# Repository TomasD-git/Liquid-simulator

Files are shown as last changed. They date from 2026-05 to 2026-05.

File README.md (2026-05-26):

# Liquid-simulator
Basically simulates liquid using imu and esp32 C6






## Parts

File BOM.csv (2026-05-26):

Name | Purpose | Quantity | Total Cost (USD) | Link | Distributor
Mini hot plate | will be used to melt the solder paste to connect components to pcb | 1 | 39.54 | https://www.aliexpress.com/item/1005007987545003.html | Aliexpress
Screen | on the screen is the actual simulation | 1 | 3.74 | https://www.aliexpress.com/item/1005004482028005.html | Aliexpress
PCB + Stencil | actual pcb which all components will be on | 1 | 36.62 | https://jlcpcb.com | JLCPCB
LCSC parts | all individual parts | 1 | 24.01 | https://lcsc.com | lcsc

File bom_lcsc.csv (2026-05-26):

Designator | Footprint | Quantity | Value | LCSC Part #
C1, C3, C5 | 0603 | 3 | 10uF | C1691
C10, C23 | 0402 | 2 | 1uF | C52923
C13, C24, C25, C7, C8, C9 | 0402 | 6 | 100nf | C1525
C2, C4 | 0603 | 2 | 1uF | C15849
C6 | 0805 | 1 | 47uF | C16780
J2 | PinHeader_1x07_P2.54mm_Vertical | 1 | Display 1.28 Inch
R1, R2 | 0402 | 2 | 22 | C25092
R10, R7 | 0402 | 2 | 5.1K | C25905
R3, R4 | 0402 | 2 | 2.2K | C25879
R5, R8 | 0402 | 2 | 10K | C25744
R6 | 0402 | 1 | 330 | C25104
SW1, SW2 | SW_Push_1P1T_XKB_TS-1187A | 2 | SW_Push | C318884
U1 | USB-C-SMD_G-SWITCH_GT-USB-7010ASV | 1 | GT-USB-7010ASV | C2988369
U2 | SOT-23-5 | 1 | AP2112K-3.3 | C51118
U4 | XDCR_BMI270 | 1 | BMI270 | C2836813
U5 | ESP32-C6-MINI-1 | 1 | ESP32-C6-MINI-1/U | C5736265

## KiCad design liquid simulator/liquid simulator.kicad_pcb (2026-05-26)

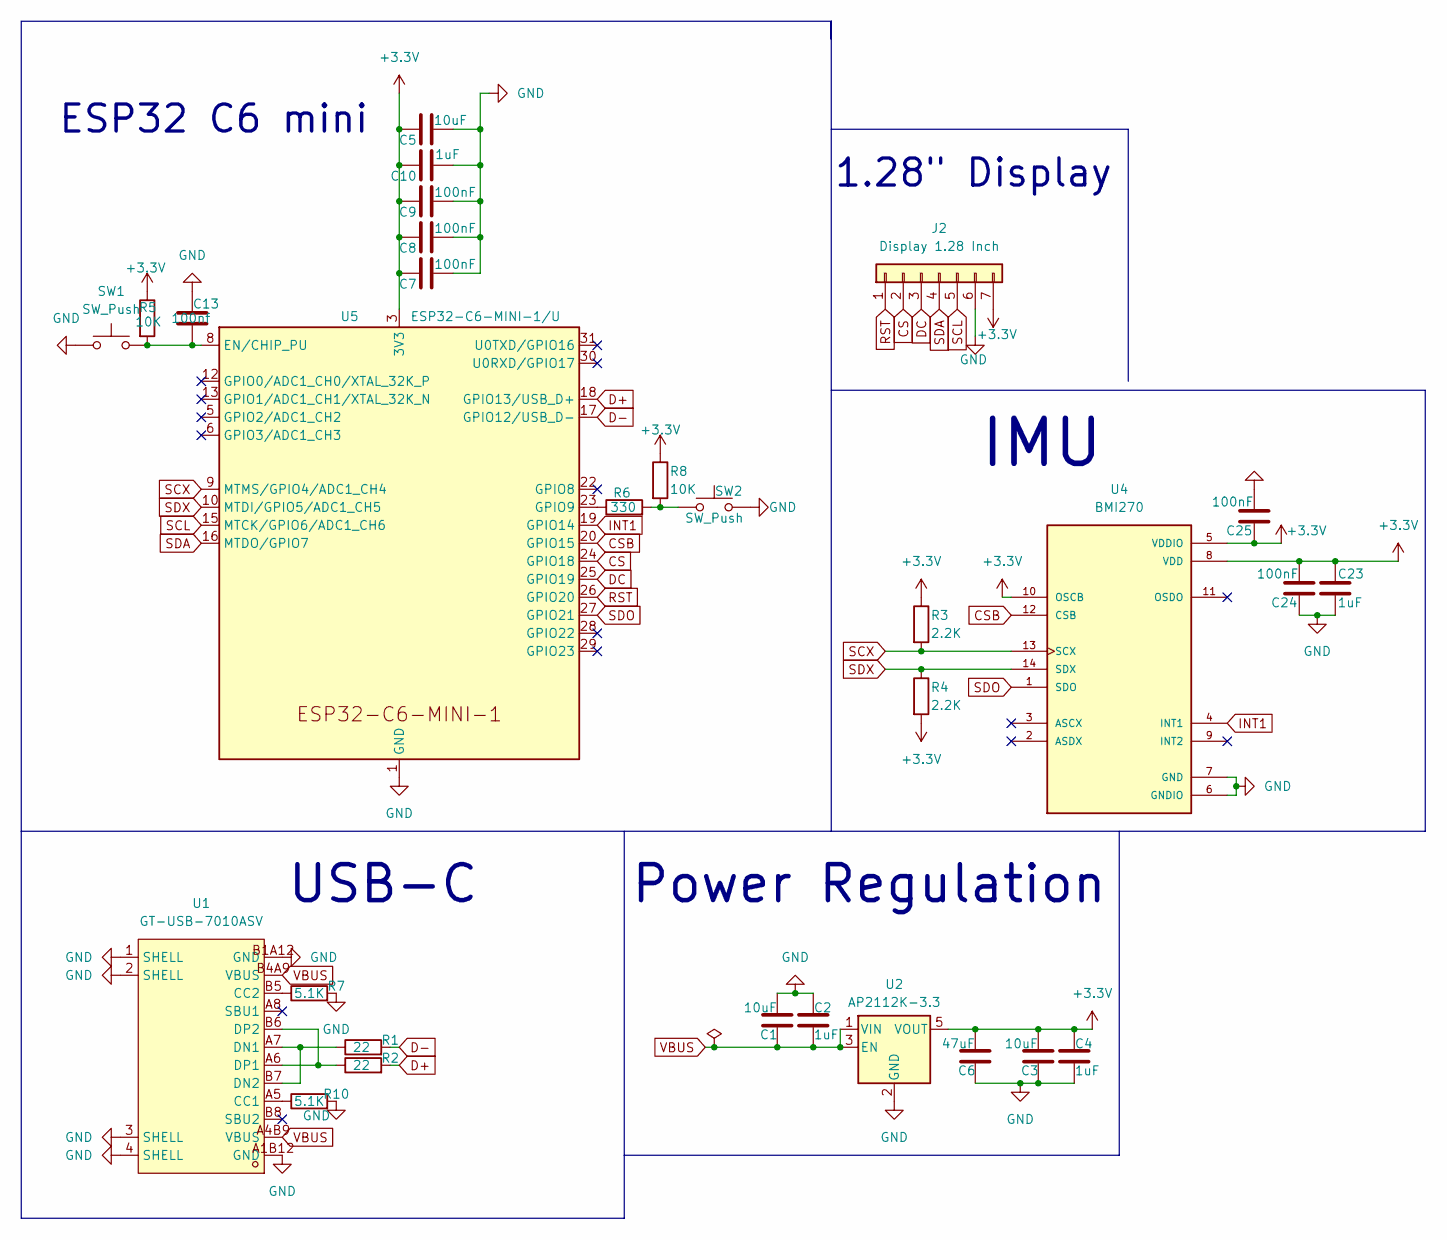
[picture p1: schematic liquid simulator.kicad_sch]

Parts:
C1, C3, C5: 10uF; C_0603_1608Metric
C2, C4: 1uF; C_0603_1608Metric
C6: 47uF; C_0805_2012Metric
C7, C8, C9, C24, C25: 100nF; C_0402_1005Metric
C10, C23: 1uF; C_0402_1005Metric
C13: 100nf; C_0402_1005Metric
J2: Display 1.28 Inch; PinHeader_1x07_P2.54mm_Vertical
R1, R2: 22; R_0402_1005Metric
R3, R4: 2.2K; R_0402_1005Metric
R5, R8: 10K; R_0402_1005Metric
R6: 330; R_0402_1005Metric
R7, R10: 5.1K; R_0402_1005Metric
SW1, SW2: SW_Push; SW_Push_1P1T_XKB_TS-1187A
U1: GT-USB-7010ASV; USB-C-SMD_G-SWITCH_GT-USB-7010ASV; MPN GT-USB-7010ASV; LCSC Part C2988369
U2: AP2112K-3.3; SOT-23-5
U4: BMI270; XDCR_BMI270
U5: ESP32-C6-MINI-1/U; ESP32-C6-MINI-1

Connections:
+3.3V: C3.1, C4.1, C5.1, C6.1, C7.1, C8.1, C9.1, C10.1, C23.1, C24.1, C25.2, J2.7, R3.1, R4.2, R5.1, R8.1, U2.5 (VOUT), U4.5 (VDDIO), U4.8 (VDD), U4.10 (OSCB), U5.3 (3V3)
CS: J2.2, U5.24 (GPIO18)
CSB: U4.12 (CSB), U5.20 (GPIO15)
D+: R2.2, U5.18 (GPIO13/USB_D+)
D-: R1.2, U5.17 (GPIO12/USB_D-)
DC: J2.3, U5.25 (GPIO19)
GND: C1.1, C2.1, C3.2, C4.2, C5.2, C6.2, C7.2, C8.2, C9.2, C10.2, C13.1, C23.2, C24.2, C25.1, J2.6, R7.2, R10.2, SW1.1, SW2.2, U1.1 (SHELL), U1.2 (SHELL), U1.3 (SHELL), U1.4 (SHELL), U1.A1B12 (GND), U1.B1A12 (GND), U2.2 (GND), U4.6 (GNDIO), U4.7 (GND), U5.1 (GND), U5.2 (GND), U5.11 (GND), U5.14 (GND), U5.36 (GND), U5.37 (GND), U5.38 (GND), U5.39 (GND), U5.40 (GND), U5.41 (GND), U5.42 (GND), U5.43 (GND), U5.44 (GND), U5.45 (GND), U5.46 (GND), U5.47 (GND), U5.48 (GND), U5.49 (GND), U5.50 (GND), U5.51 (GND), U5.52 (GND), U5.53 (GND)
INT1: U4.4 (INT1), U5.19 (GPIO14)
unnamed: R6.2, R8.2, SW2.1
unnamed: R10.1, U1.A5 (CC1)
unnamed: R7.1, U1.B5 (CC2)
unnamed: R1.1, U1.A7 (DN1), U1.B7 (DN2)
unnamed: R2.1, U1.A6 (DP1), U1.B6 (DP2)
unnamed: C13.2, R5.2, SW1.2, U5.8 (EN/CHIP_PU)
unnamed: R6.1, U5.23 (GPIO9)
RST: J2.1, U5.26 (GPIO20)
SCL: J2.5, U5.15 (MTCK/GPIO6/ADC1_CH6)
SCX: R3.2, U4.13 (SCX), U5.9 (MTMS/GPIO4/ADC1_CH4)
SDA: J2.4, U5.16 (MTDO/GPIO7)
SDO: U4.1 (SDO), U5.27 (GPIO21)
SDX: R4.1, U4.14 (SDX), U5.10 (MTDI/GPIO5/ADC1_CH5)
VBUS: C1.2, C2.2, U1.A4B9 (VBUS), U1.B4A9 (VBUS), U2.1 (VIN), U2.3 (EN)

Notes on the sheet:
IMU
ESP32 C6 mini
Power Regulation
1.28" Display
USB-C

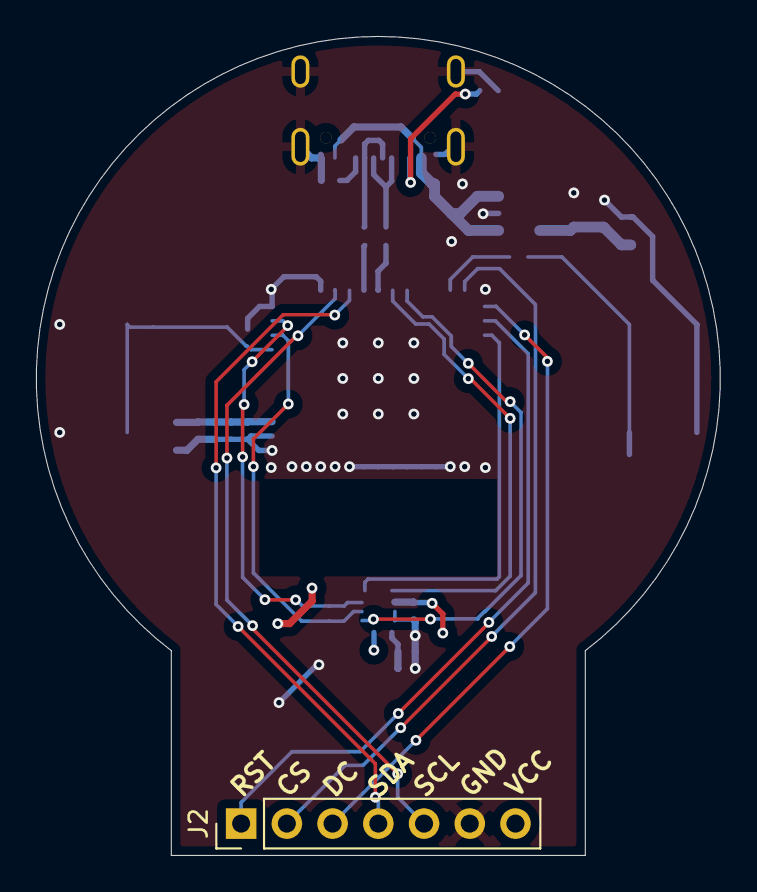
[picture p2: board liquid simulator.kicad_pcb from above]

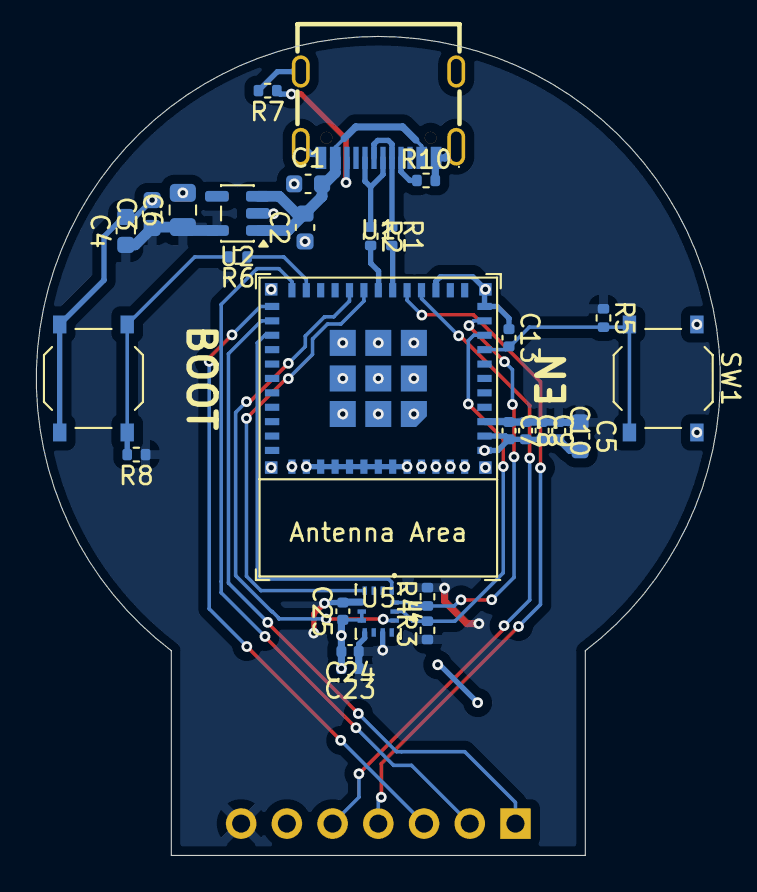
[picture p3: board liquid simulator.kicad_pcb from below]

Board: 2 copper layers, 38.0 x 45.5 mm, 30 parts (29 on the bottom side), 22 nets.

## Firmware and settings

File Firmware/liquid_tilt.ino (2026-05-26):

#include <Arduino.h>
#include <SPI.h>
#include <LovyanGFX.hpp>
#include "lgfx_user.hpp"

LGFX tft;
LGFX_Sprite fb(&tft);


// IMU PINS

#define PIN_IMU_SCK   4
#define PIN_IMU_MOSI  5
#define PIN_IMU_MISO  21
#define PIN_IMU_CS    15
#define PIN_IMU_INT1  14
#define PIN_BTN       9

#define HAVE_BMI270
#include "bmi270_config_file.h"


static SPIClass imuSPI(SPI);

static const int W = 240;
static const int H = 240;
static const int CX = 120;
static const int CY = 120;
static const float RING_R = 116.0f;

static const int NP = 90;
static const float PR = 8.5f;
static const float INTERACT = 22.0f;
static const float I2 = INTERACT * INTERACT;
static const float WALL = RING_R - PR - 1.5f;
static const float DAMP = 0.965f;
static const float G_SCALE = 3.2f;
static const float LP_ALPHA = 0.14f;

struct Particle { float x,y,vx,vy; };
static Particle p[NP];

static float imu_ax = 0;
static float imu_ay = 0;

#define BMI270_REG_CHIP_ID 0x00
#define BMI270_REG_ACC_DATA 0x0C
#define BMI270_REG_ACC_CONF 0x40
#define BMI270_REG_ACC_RANGE 0x41
#define BMI270_REG_PWR_CTRL 0x7D
#define BMI270_REG_PWR_CONF 0x7C
#define BMI270_REG_CMD 0x7E
#define BMI270_REG_INIT_CTRL 0x59
#define BMI270_REG_INIT_ADDR_0 0x5B
#define BMI270_REG_INIT_ADDR_1 0x5C
#define BMI270_REG_INIT_DATA 0x5E
#define BMI270_REG_INTERNAL_STATUS 0x21

static void imuWrite(uint8_t reg, uint8_t val) {
  digitalWrite(PIN_IMU_CS, LOW);
  imuSPI.transfer(reg & 0x7F);
  imuSPI.transfer(val);
  digitalWrite(PIN_IMU_CS, HIGH);
}

static uint8_t imuRead(uint8_t reg) {
  digitalWrite(PIN_IMU_CS, LOW);
  imuSPI.transfer(reg | 0x80);
  imuSPI.transfer(0x00);
  uint8_t v = imuSPI.transfer(0x00);
  digitalWrite(PIN_IMU_CS, HIGH);
  return v;
}

static void imuBurst(uint8_t reg, uint8_t* buf, uint8_t n) {
  digitalWrite(PIN_IMU_CS, LOW);
  imuSPI.transfer(reg | 0x80);
  imuSPI.transfer(0x00);
  for (int i = 0; i < n; i++) buf[i] = imuSPI.transfer(0x00);
  digitalWrite(PIN_IMU_CS, HIGH);
}

bool initBMI270() {
  imuSPI.begin(PIN_IMU_SCK, PIN_IMU_MISO, PIN_IMU_MOSI);
  imuSPI.setFrequency(8000000);
  pinMode(PIN_IMU_CS, OUTPUT);
  digitalWrite(PIN_IMU_CS, HIGH);
  delay(20);
  imuWrite(BMI270_REG_CMD, 0xB6);
  delay(20);
  if (imuRead(BMI270_REG_CHIP_ID) != 0x24) {
    Serial.println("BMI270 not found");
    return false;
  }
#ifdef HAVE_BMI270
  imuWrite(BMI270_REG_INIT_CTRL, 0x00);
  for (uint16_t off = 0; off < bmi270_config_file_size; off += 256) {
    uint16_t half = off >> 1;
    imuWrite(BMI270_REG_INIT_ADDR_0, half & 0xFF);
    imuWrite(BMI270_REG_INIT_ADDR_1, half >> 8);
    digitalWrite(PIN_IMU_CS, LOW);
    imuSPI.transfer(BMI270_REG_INIT_DATA & 0x7F);
    for (int i = 0; i < 256 && (off + i) < bmi270_config_file_size; i++)
      imuSPI.transfer(bmi270_config_file[off + i]);
    digitalWrite(PIN_IMU_CS, HIGH);
  }
#endif

  imuWrite(BMI270_REG_INIT_CTRL, 0x01);
  delay(100);

  imuWrite(BMI270_REG_ACC_CONF, 0xA8);
  imuWrite(BMI270_REG_ACC_RANGE, 0x00);
  imuWrite(BMI270_REG_PWR_CTRL, 0x04);
  imuWrite(BMI270_REG_PWR_CONF, 0x02);

  return true;
}
// READ IMU
void readIMU() {
  uint8_t b[6];
  imuBurst(BMI270_REG_ACC_DATA, b, 6);

  int16_t ax = (int16_t)(b[1] << 8 | b[0]);
  int16_t ay = (int16_t)(b[3] << 8 | b[2]);

  float fx = ax / 16384.0f;
  float fy = ay / 16384.0f;

  imu_ax += LP_ALPHA * (fx - imu_ax);
  imu_ay += LP_ALPHA * (fy - imu_ay);
}
// PARTICLES
void initParticles() {
  for (int i=0;i<NP;i++) {
    float r = sqrt((i+1.0)/NP) * WALL * 0.6f;
    float a = i * 2.399963f;
    p[i] = {
      CX + r*cos(a),
      CY + r*sin(a),
      0,0
    };
  }
}
// PHYSICS
void physics(float gx, float gy) {
  for (int i=0;i<NP;i++) {
    p[i].vx += gx * 0.016f;
    p[i].vy += gy * 0.016f;
    for (int j=i+1;j<NP;j++) {
      float dx = p[i].x - p[j].x;
      float dy = p[i].y - p[j].y;
      float d2 = dx*dx + dy*dy;
      if (d2 < I2 && d2 > 0.1f) {
        float d = sqrt(d2);
        float f = (INTERACT - d)/INTERACT * 0.5f;
        float nx = dx/d * f;
        float ny = dy/d * f;
        p[i].vx += nx; p[i].vy += ny;
        p[j].vx -= nx; p[j].vy -= ny;
      }
    }
  }
  for (int i=0;i<NP;i++) {
    p[i].vx *= DAMP;
    p[i].vy *= DAMP;
    p[i].x += p[i].vx;
    p[i].y += p[i].vy;
    float dx = p[i].x - CX;
    float dy = p[i].y - CY;
    float d = sqrt(dx*dx + dy*dy);
    if (d > WALL) {
      float nx = dx/d;
      float ny = dy/d;
      p[i].x = CX + nx * WALL;
      p[i].y = CY + ny * WALL;
      float dot = p[i].vx*nx + p[i].vy*ny;
      p[i].vx -= 1.8f * dot * nx;
      p[i].vy -= 1.8f * dot * ny;
    }
  }
}
// RENDER
void render() {
  fb.fillScreen(TFT_BLACK);
  fb.fillCircle(CX,CY,118, fb.color565(2,5,22));
  for (int i=0;i<NP;i++) {
    fb.fillCircle(p[i].x,p[i].y,8, fb.color565(0,180,255));
  }
  fb.pushSprite(0,0);
}
// SETUP
void setup() {
  Serial.begin(115200);
  tft.init();
  tft.setRotation(0);
  fb.setColorDepth(16);
  fb.createSprite(W,H);
  pinMode(PIN_IMU_CS, OUTPUT);
  digitalWrite(PIN_IMU_CS, HIGH);
  initParticles();
  if (initBMI270())
    Serial.println("IMU OK");
  else
    Serial.println("IMU FAIL → demo mode");
}
// LOOP
void loop() {
  readIMU();
  // Tune this if wrong orintation
  float gx = -imu_ax * G_SCALE;
  float gy =  imu_ay * G_SCALE;
  physics(gx, gy);
  render();
}

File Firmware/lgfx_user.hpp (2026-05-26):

#pragma once
#include <LovyanGFX.hpp>

class LGFX : public lgfx::LGFX_Device {
  lgfx::Panel_GC9A01 _panel;
  lgfx::Bus_SPI _bus;
  
public:
  LGFX(void) {
    {
      auto cfg = _bus.config();
      cfg.spi_host = SPI2_HOST;  
      cfg.spi_mode = 0;
      cfg.freq_write = 80000000;
      cfg.freq_read  = 16000000;
      cfg.pin_sclk = 4;
      cfg.pin_mosi = 6;
      cfg.pin_miso = -1;
      cfg.pin_dc   = 19;
      _bus.config(cfg);
      _panel.setBus(&_bus);
    }
    {
      auto cfg = _panel.config();
      cfg.pin_cs   = 18;
      cfg.pin_rst  = 20;
      cfg.pin_busy = -1;
      cfg.memory_width  = 240;
      cfg.memory_height = 240;
      cfg.panel_width  = 240;
      cfg.panel_height = 240;
      cfg.offset_x = 0;
      cfg.offset_y = 0;
      cfg.invert = false;
      cfg.rgb_order = false;
      _panel.config(cfg);
    }
    setPanel(&_panel);
  }
};

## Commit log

2026-05-26 added schematic + bom_lcsc
    [bom_lcsc.csv, designators.csv, liquid simulator.kicad_pcb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]
2026-05-26 added pcb file
2026-05-26 added main BOM
    [BOM.csv]
